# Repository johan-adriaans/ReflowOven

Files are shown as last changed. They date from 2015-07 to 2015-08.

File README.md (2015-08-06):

# ReflowOven
Arduino reflow oven voor de BEEA avond, 6 augustus 2015

De "bill-of-materials" staat [hier](board-v1/bill-of-materials.pdf).

## Opbouw reflow printje

Dit zijn de verbindingen op het bordje dat je gaat opbouwen:

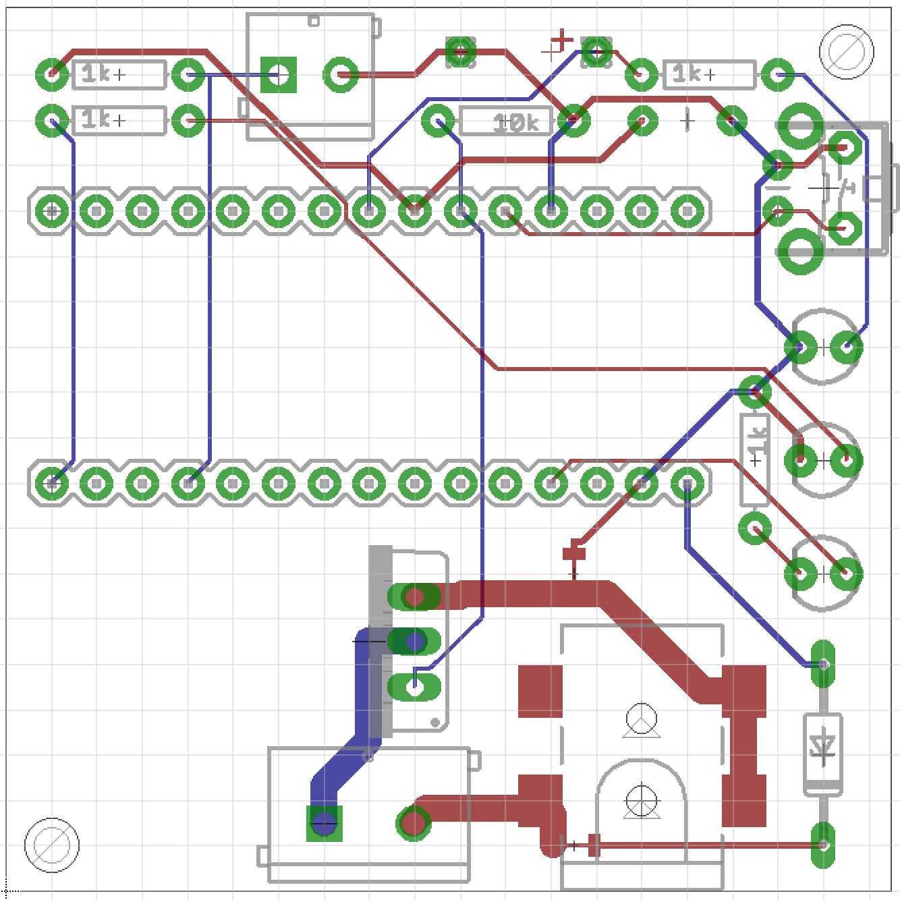
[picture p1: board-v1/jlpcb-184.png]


### Stap 1: alle lage componenten

Let op de polariteit van de 3 LEDs en de zener diode!

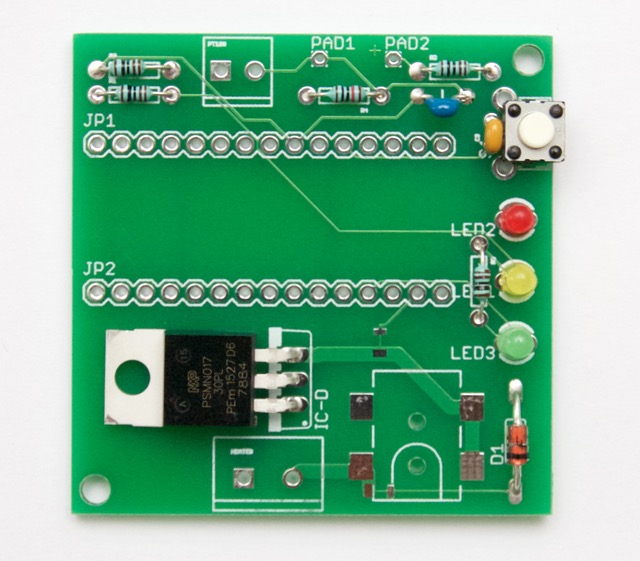
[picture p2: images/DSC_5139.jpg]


Het knopje is een andere dan oorspronkelijk op de print voorzien is.

### Stap 2: drie connectoren

DC jack, kleine sensor aansluiting, grote heater aansluting:

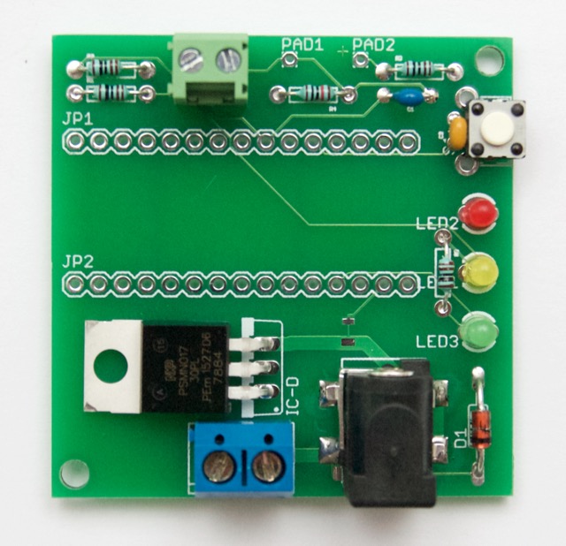
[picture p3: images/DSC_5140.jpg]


Goed vastsolderen, vooral die DC voeding jack.

### Stap 3: Arduino Nano microcontroller

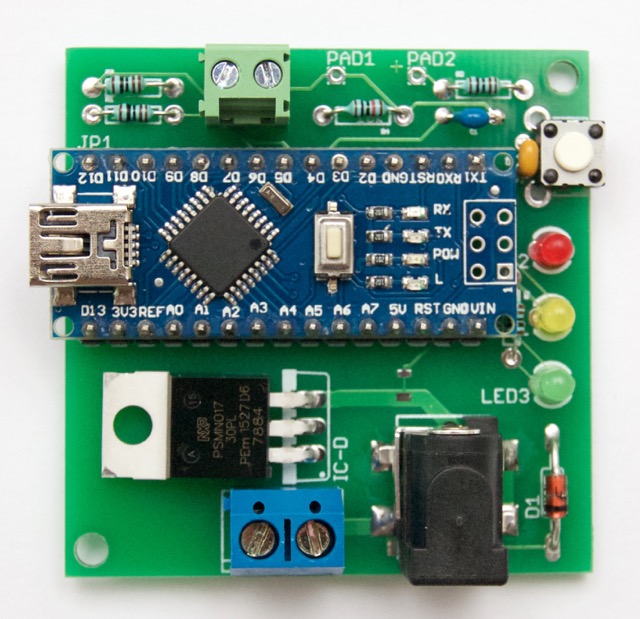
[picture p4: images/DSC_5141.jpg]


Pennen afknippen, zodat de onderkant redelijk vlak is.

### Stap 4: zoemer en extra dikke condensator

Let op polariteit van beide componenten:

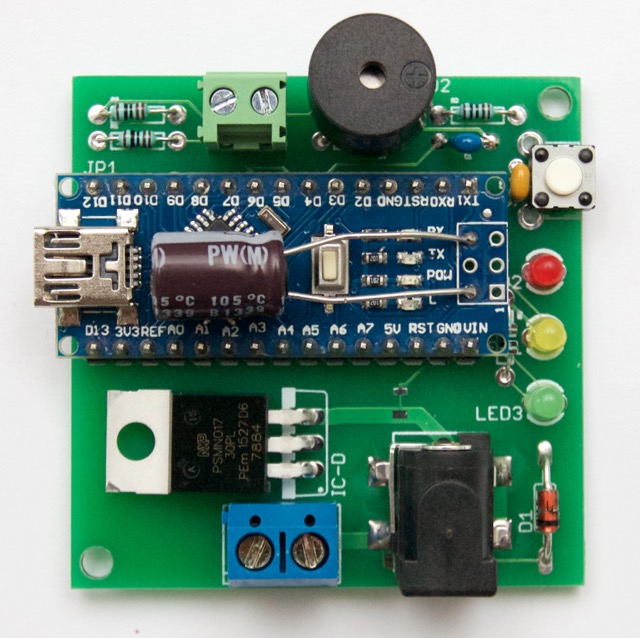
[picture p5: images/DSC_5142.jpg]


### Stap 5: sensor + heater

De sensor in de groene schroefklemmen, heater in de blauwe:

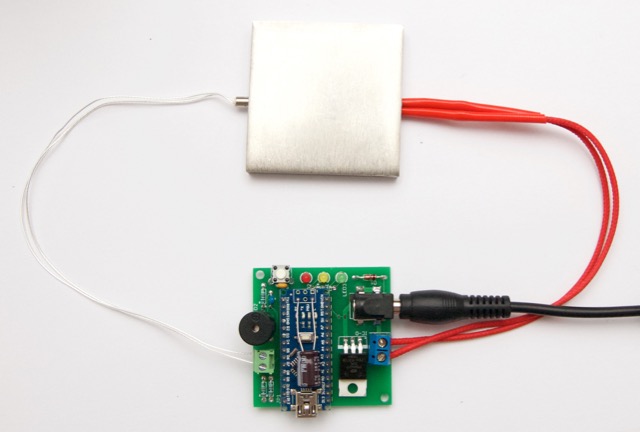
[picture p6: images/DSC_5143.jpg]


Draden blank maken, liefst strippen en vertinnen, dan goed vastschroeven.

### Stap 6: software

Er moet een Arduino "sketch" in de Arduino worden geinstalleerd.  
Dat gaat via de USB stekker, en een USB driver voor de CH341 chip.  
De groene LED is altijd aan als de interne 5V regelaar stroom krijgt.

**Niet** de 19V voeding aansluiten tijdens deze actie!

### Stap 7

Controleren, controleren, controleren. En dan: _nog een laatste keertje..._  
Als bijvoorbeeld de zener verkeerd om zit, krijg je gegarandeerd vuurwerk.  
Pas als je zeker weet dat de zaak klopt, de 19V adapter inprikken.

Als alles goed aangesloten en ingesteld is, begint het plaatje warm te worden.  
Zet de zaak **alleen** aan als de heater goed in het koelblok geklemd zit!

## Opbouw demo bordje

...

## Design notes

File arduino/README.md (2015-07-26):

# ReflowOven
Arduino reflow oven voor de BEEA avond

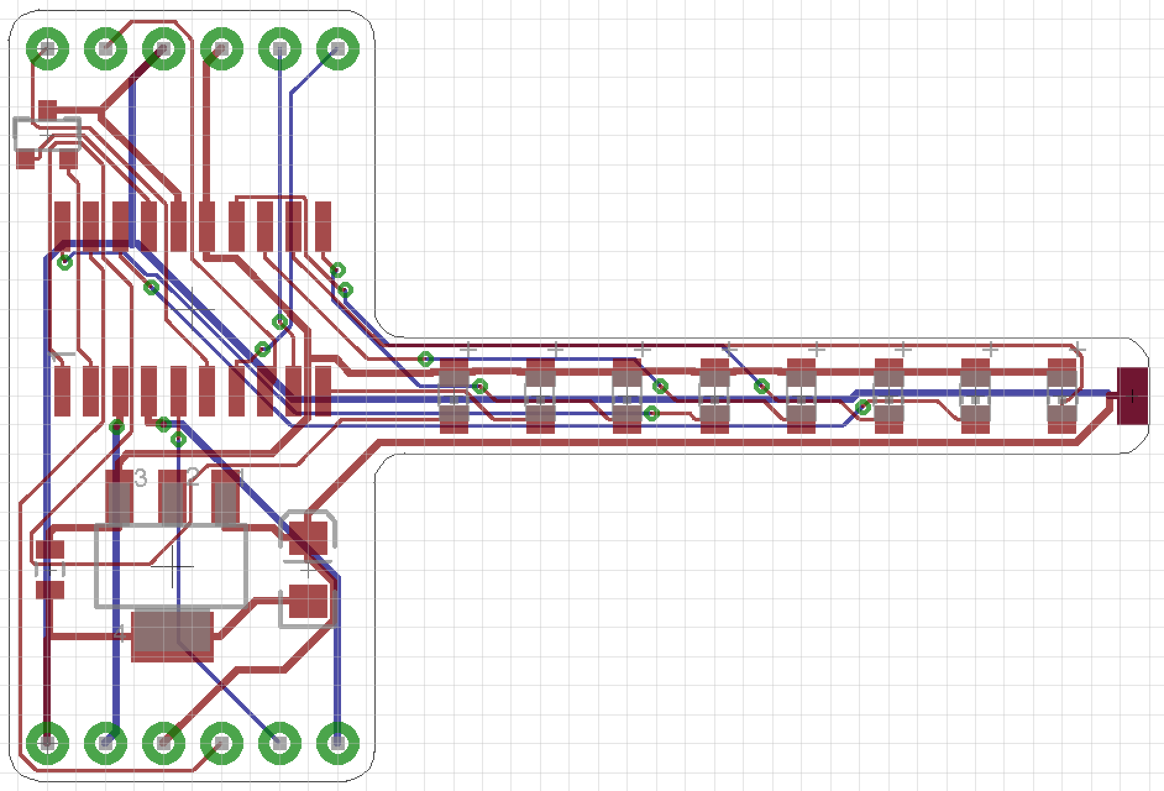
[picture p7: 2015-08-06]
demo-v1/jlpcb-183.png

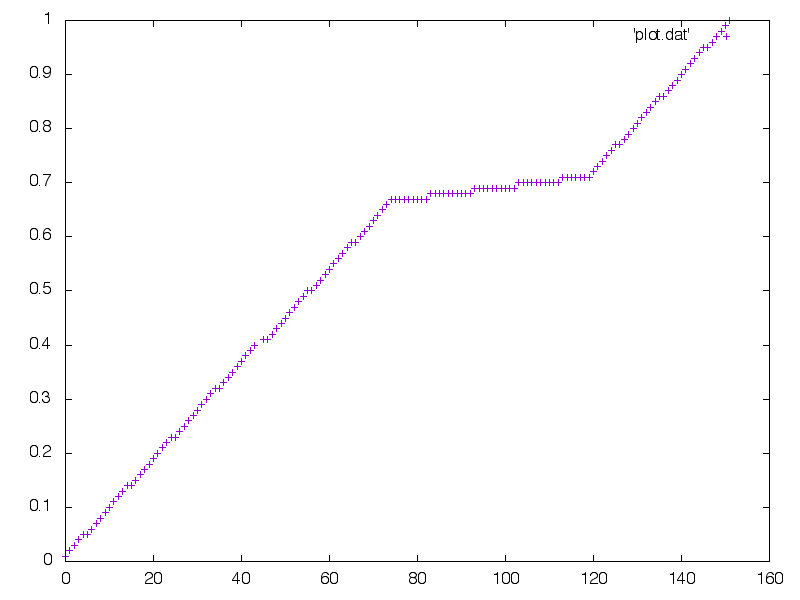
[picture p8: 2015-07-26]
research/plot.png

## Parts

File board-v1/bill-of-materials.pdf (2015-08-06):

Component | Cost US$
Arduino Nano clone (eBay) | 2.68
buzzer | 0.16
heater cartridge 40W | 2.24
PT100 temperature sensor | 1.02
zener 10V 1W | 0.40
capacitor 470 µF 10V | 0.15
MOSFET PSMN017-30PL | 0.75
power supply 19V 65W | 11.00
capacitor 1 µF 16V | 0.23
4x resistor 1 kΩ 1/8W | 0.15
resistor 10 kΩ 1/8W | 0.04
2x screw terminals | 0.60
3x LED 3mm | 1.50
DC power jack 5.5/2.1 mm | 0.90
push button | 0.23
printed circuit board | 2.10
Electronics | 24.15
LPC812 SOIC µ-controller | 1.80
8x blue LED | 2.80
hall effect sensor S-5716 | 1.05
regulator MIC5203-3.6 | 0.95
capacitor 1 µF ceramic | 0.23
capacitor 10 µF ceramic | 0.27
USB cable | 1.00
printed circuit board | 2.10
Demo board | 10.20
tweezers | 0.99
glow-in-the-dark paint | 1.69
heat sink | 1.77
solder paste low-melt 138°C | 1.65
55x55x8mm aluminium block | 2.00
syringe 1 ml | 1.00
2x syringe nozzle | 1.10
ceramic tile | 1.00
crème brûlée + schaaltje :) | 1.10
Mechanical | 12.30
Various | 5.00
Nano Reflow v1 - BEEA | 51.65

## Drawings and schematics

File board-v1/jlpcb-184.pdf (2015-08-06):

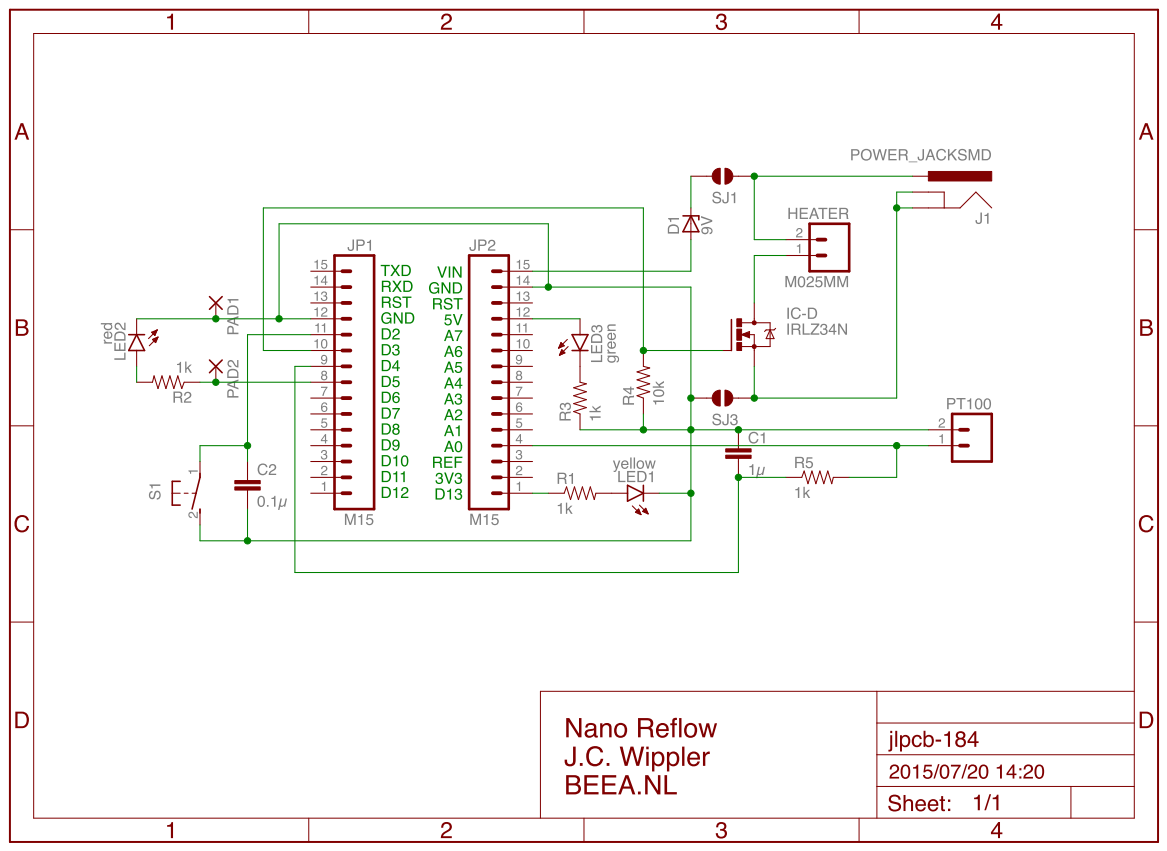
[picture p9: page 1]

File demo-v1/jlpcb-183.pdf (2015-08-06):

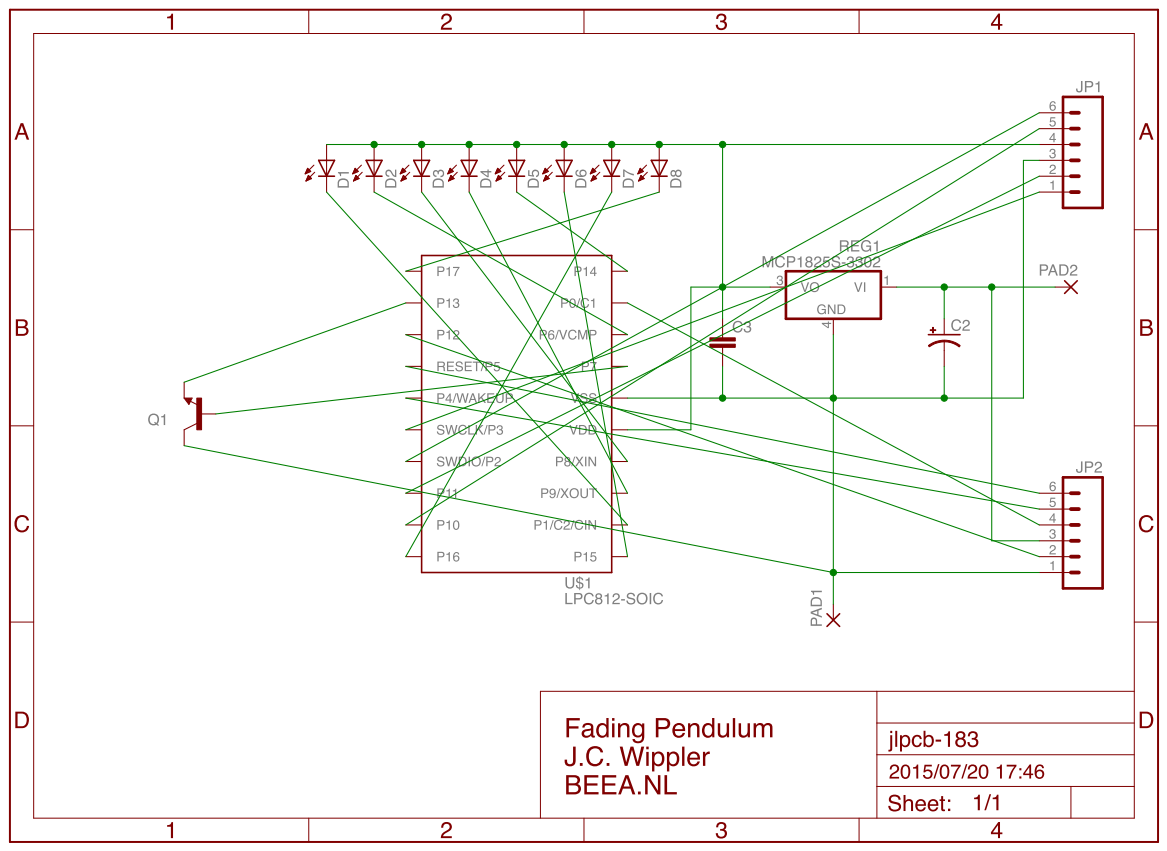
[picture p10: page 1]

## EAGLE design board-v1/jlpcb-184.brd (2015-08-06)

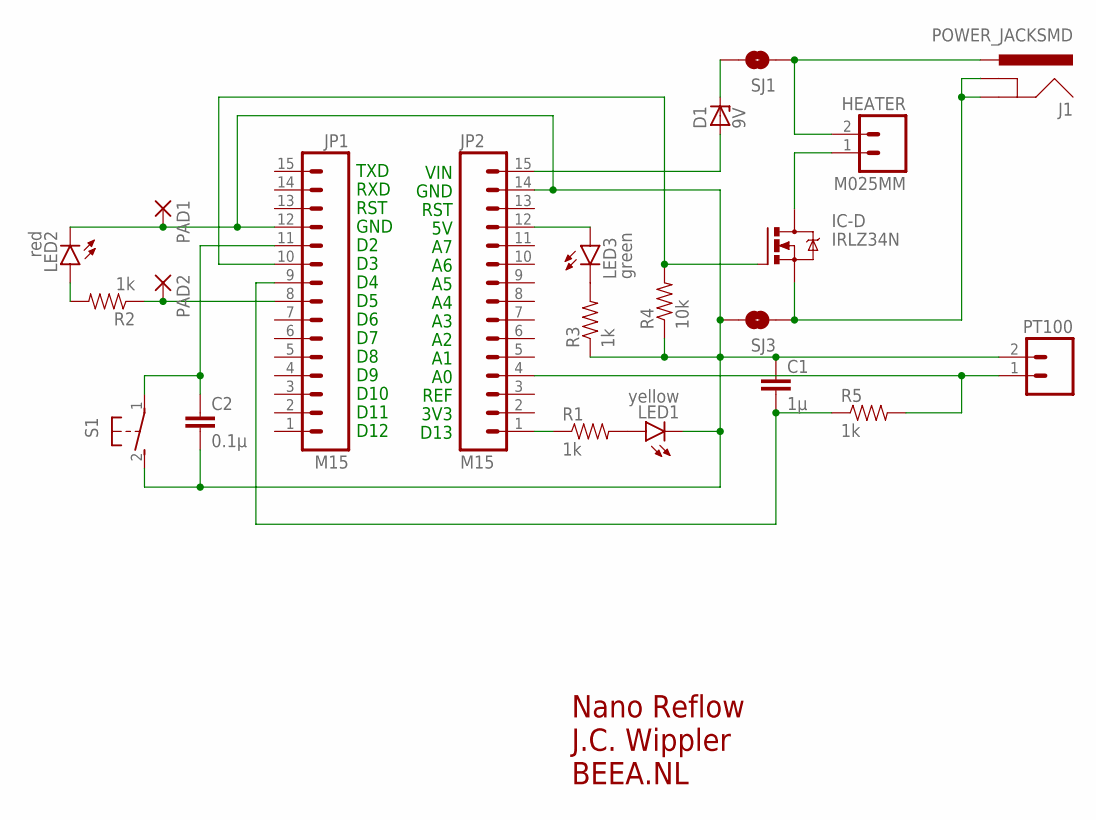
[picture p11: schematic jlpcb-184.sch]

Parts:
C1: 1µ; CAP-PTH-5MM
C2: 0.1µ; CAP-PTH-SMALL
D1: 9V; DO35Z10
HEATER: M025MM; SCREWTERMINAL-5MM-2
IC-D: IRLZ34N; TO220BV
J1: POWER_JACKSMD; POWER_JACK_SMD
JP1, JP2: M15; 1X15
LED1: yellow; LED3MM
LED2: red; LED3MM
LED3: green; LED3MM
PAD1, PAD2: 1,6/0,8
PT100: M023.5MM; SCREWTERMINAL-3.5MM-2
R1, R2, R3, R5: 1k; AXIAL-0.3
R4: 10k; AXIAL-0.3
S1: 31-XX; B3F-31XX
SJ1, SJ3: SOLDERJUMPERTRACE; SJ_2S-TRACE

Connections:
unnamed: D1.A, JP2.15
unnamed: D1.C, SJ1.2
unnamed: HEATER.1, IC-D.D
unnamed: IC-D.S, J1.GND (GNDBREAK), J1.P$4 (GND), SJ3.1
unnamed: C1.1, C2.2, JP1.12, JP2.14, LED1.K (C), LED2.K (C), PAD1.1, PT100.2, R3.P$1 (1), R4.P$1 (1), S1.2 (S), SJ3.2
unnamed: HEATER.2, J1.VIN0 (PWR), SJ1.1
unnamed: LED2.A, R2.P$2 (2)
unnamed: LED1.A, R1.P$2 (2)
unnamed: JP2.1, R1.P$1 (1)
unnamed: JP2.4, PT100.1, R5.P$2 (2)
unnamed: LED3.K (C), R3.P$2 (2)
unnamed: JP2.12, LED3.A
unnamed: IC-D.G, JP1.10, R4.P$2 (2)
unnamed: JP1.8, PAD2.1, R2.P$1 (1)
unnamed: C1.2, JP1.9, R5.P$1 (1)
unnamed: C2.1, JP1.11, S1.1

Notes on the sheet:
D12
D11
D10
GND
RST
RXD
TXD
D13
3V3
REF
VIN
Nano Reflow J.C. Wippler BEEA.NL

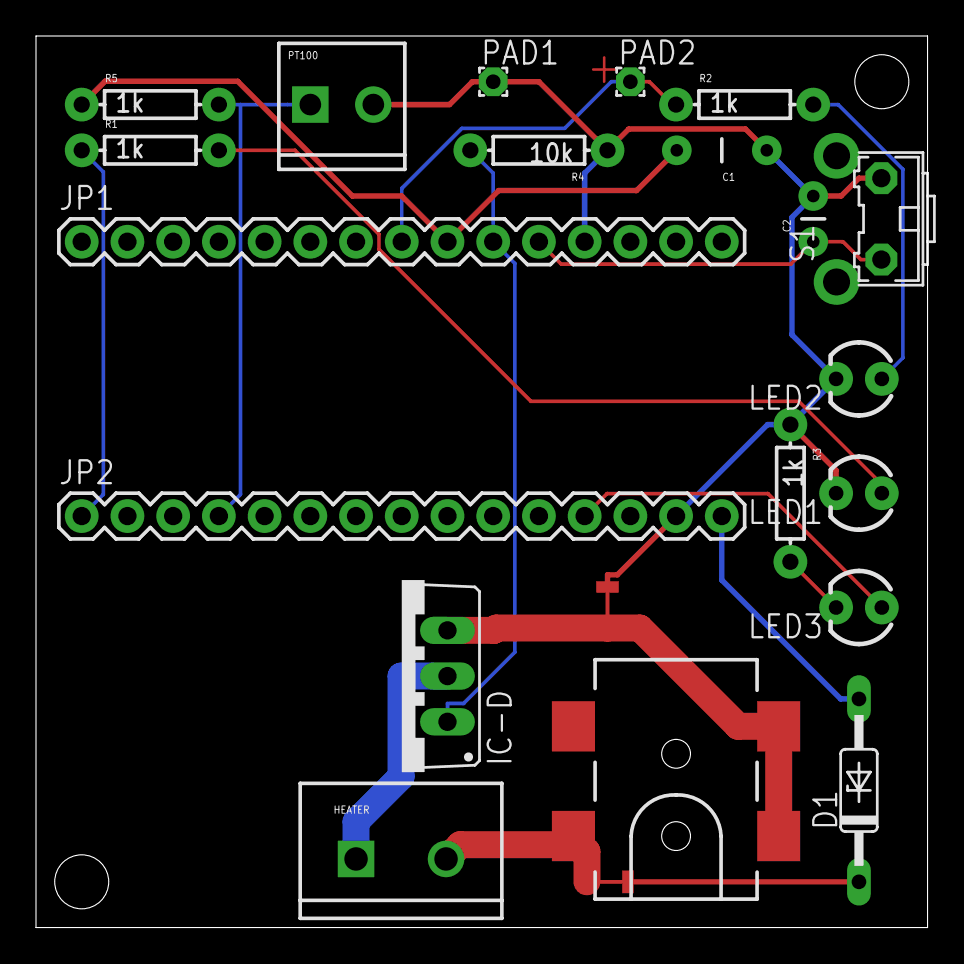
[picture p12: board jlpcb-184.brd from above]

Board: 2 copper layers, 49.5 x 49.5 mm, 22 parts (0 on the bottom side), 16 nets.

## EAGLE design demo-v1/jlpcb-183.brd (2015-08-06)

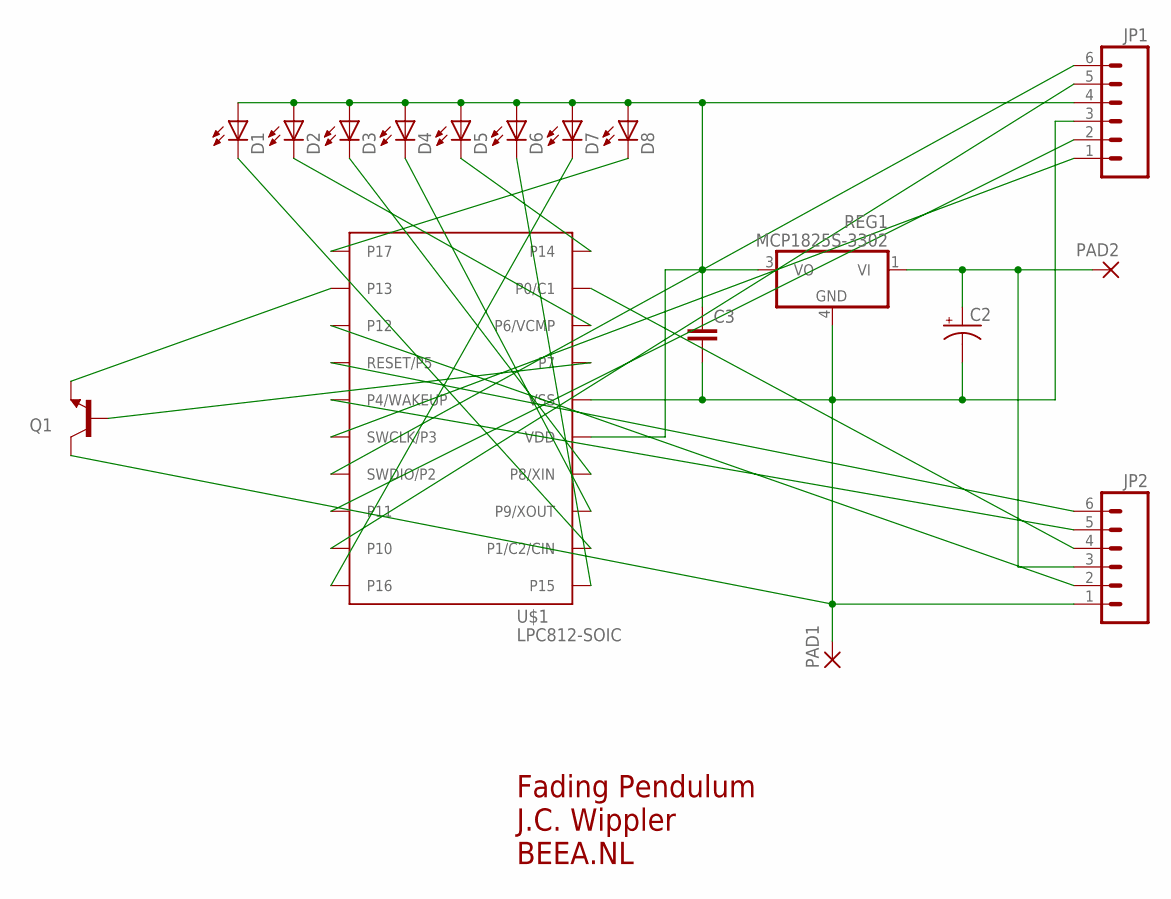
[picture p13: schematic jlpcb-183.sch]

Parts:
C2: CAP_POL1206; EIA3216
C3: CAP0805; 0805
D1, D2, D3, D4, D5, D6, D7, D8: LEDCHIP-LED0805; CHIP-LED0805
JP1, JP2: M06NO_SILK_FEMALE_PTH; 1X06_NO_SILK
PAD1, PAD2: SMD2; SMD1,27-2,54
Q1: TRANSISTOR_NPNSOT23-3; SOT23-3
REG1: MCP1825S-3302; SOT223
U$1: LPC812-SOIC; SOIC20

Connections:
unnamed: D1.C, U$1.12 (P1/C2/CIN)
unnamed: D2.C, U$1.18 (P6/VCMP)
unnamed: D3.C, U$1.14 (P8/XIN)
unnamed: D4.C, U$1.13 (P9/XOUT)
unnamed: D5.C, U$1.20 (P14)
unnamed: D6.C, U$1.11 (P15)
unnamed: D7.C, U$1.10 (P16)
unnamed: D8.C, U$1.1 (P17)
unnamed: C3.1, D1.A, D2.A, D3.A, D4.A, D5.A, D6.A, D7.A, D8.A, JP1.4, REG1.3 (VO), U$1.15 (VDD)
unnamed: C2.C (-), C3.2, JP1.3, JP2.1, PAD1.1, Q1.3 (C), REG1.4 (GND), U$1.16 (VSS)
unnamed: C2.A (+), JP2.3, PAD2.1, REG1.1 (VI)
unnamed: JP2.2, U$1.3 (P12)
unnamed: JP2.6, U$1.4 (RESET/P5)
unnamed: JP2.5, U$1.5 (P4/WAKEUP)
unnamed: JP2.4, U$1.19 (P0/C1)
unnamed: JP1.5, U$1.9 (P10)
unnamed: JP1.2, U$1.8 (P11)
unnamed: JP1.6, U$1.7 (SWDIO/P2)
unnamed: JP1.1, U$1.6 (SWCLK/P3)
unnamed: Q1.2 (E), U$1.2 (P13)
unnamed: Q1.1 (B), U$1.17 (P7)

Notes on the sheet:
Fading Pendulum J.C. Wippler BEEA.NL

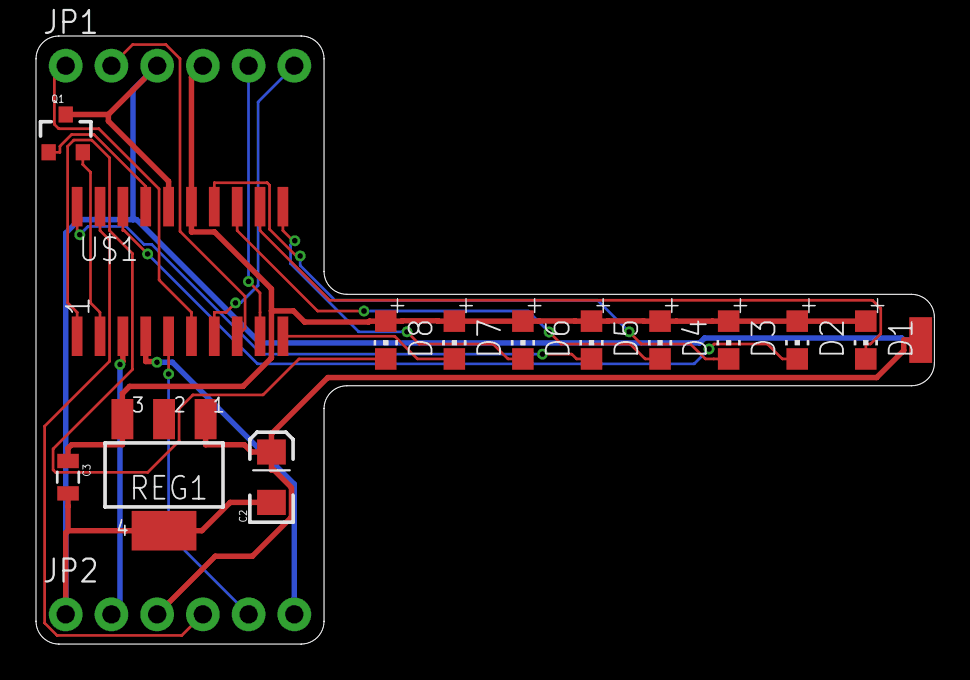
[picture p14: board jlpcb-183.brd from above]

Board: 2 copper layers, 49.9 x 33.8 mm, 17 parts (1 on the bottom side), 21 nets.

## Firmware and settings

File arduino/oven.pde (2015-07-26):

#define STAGE_INITIAL 1  // Heat up to ~0.75 of target temp
#define STAGE_SOAK 2     // Soak at ~0.75 of temp for TIME_TO_SOAK seconds
#define STAGE_END 3      // Heat up to 1
#define STAGE_FINISHED 4 // Shut down heat and play buzzer
#define STAGE_ERROR 255  // Shut down heat and stop

#define MODE_NORMAL 1    // Normal operation
#define MODE_CALIBRATE 2 // Calibration mode, blink led and listen for pushbutton

// Heat profiles
// Loodvrij soldeer
//#define SOAK_TEMPERATURE 180   // At which temperature shall we start soaking?
//#define TARGET_TEMPERATURE 250 // Target temperature..

// Loodhoudende soldeer
//#define SOAK_TEMPERATURE 140
//#define TARGET_TEMPERATURE 220

// Laagsmeltpunt soldeer
#define SOAK_TEMPERATURE 110
#define TARGET_TEMPERATURE 160

#define MAX_HEAT_OFFSET 20     // Area around target heat used for calculating heater power
#define MAX_HEATER_RATE 200    // Max PWM rate for heaterPin

#define TIME_TO_SOAK 45.0 // Seconds to soak (Needs to be a float)
#define TIME_BEFORE_SOAK 90.0 // Try to reach SOAK_TEMPERATURE in TIME_BEFORE_SOAK seconds

// Pinout
int pushbuttonPin = 2;
int heaterPin = 3;
int sensorPowerPin = 4;
int buzzerPin = 5;
int ledPin = 13;
int sensorInputPin = 0;

int seconds = 0;
int pushbuttonState = 0;
int soakTimeStart = 0;
int soakTime = 0;
float heaterPower = 0;
float temperature = 0;
float targetTemperature = 0;

// Start in normal mode
int mode = MODE_NORMAL;
int stage = STAGE_INITIAL;

void setup()
{
  pinMode( heaterPin, OUTPUT );
  pinMode( buzzerPin, OUTPUT );
  pinMode( ledPin, OUTPUT );
  pinMode( pushbuttonPin, INPUT_PULLUP ); // Pull-up inverts HIGH/LOW state

  // Setup sensor
  //ADMUX = 0xC0; // REFS = 3, use 1.1V bandgap as reference
  //analogReference(INTERNAL1V1);
  analogReference( 3 );
  analogRead( sensorInputPin );
  pinMode( sensorPowerPin, OUTPUT );
  digitalWrite( sensorPowerPin, 1);

  Serial.begin( 57600 );
  Serial.println( "\n[Reflow oven]" );
  Serial.println( "##### INITIAL STAGE #####" );
}

int readTemperature ()
{
  // 380 ≈ 25°C and 765 ≈ 200°C
  int adc = analogRead( sensorInputPin );

  static int avg = 0;
  if ( avg == 0 ) {
    avg = adc;
  }
  avg = (3 * avg + adc) / 4;

  // assumes linear relationship between adc and temp, this is not correct!
  return map( avg, 380, 765, 25, 200 );
}

void loop()
{
  // Error occured, needs reset
  if ( stage == STAGE_ERROR ) return;

  static int lastUpdate;
  seconds = millis() / 1000;

  // Read button
  pushbuttonState = digitalRead( pushbuttonPin );
  if ( pushbuttonState == LOW && seconds < 5 ) {
    Serial.println( "Starting calibration mode" );
    mode = MODE_CALIBRATE;
  } else if ( pushbuttonState == LOW && seconds > 30 && mode == MODE_CALIBRATE ) {
    Serial.println( "Calibrated" );
    // TODO: Write sensor measurement to EPROM and shut down
  }

  if ( stage == STAGE_INITIAL ) {
    if ( temperature >= SOAK_TEMPERATURE && stage == STAGE_INITIAL ) {
      Serial.println( "##### SOAK STAGE #####" );
      soakTimeStart = seconds;
      stage = STAGE_SOAK;
    }

    targetTemperature = (seconds / TIME_BEFORE_SOAK) * SOAK_TEMPERATURE;
    heaterPower = (targetTemperature - temperature) / MAX_HEAT_OFFSET;
  } else if ( stage == STAGE_SOAK ) {
    soakTime = seconds - soakTimeStart;
    if ( soakTime >= TIME_TO_SOAK ) {
      Serial.println( "##### END STAGE #####" );
      stage = STAGE_END;
    }

    targetTemperature = SOAK_TEMPERATURE + ((soakTime / TIME_TO_SOAK) * 10);
    heaterPower = ( targetTemperature - temperature ) / MAX_HEAT_OFFSET;
  } else if ( stage == STAGE_END ) {
    heaterPower = 1;
  }

  if ( temperature >= TARGET_TEMPERATURE && stage < STAGE_FINISHED ) {
    Serial.println( "##### FINISHED #####" );
    heaterPower = 0;
    stage = STAGE_FINISHED;
  }

  if ( seconds != lastUpdate ) {
    if ( temperature > 300 ) {
      Serial.println( "Error: heat > 300 - Please attach sensor and reset" );
      stage = STAGE_ERROR;
      digitalWrite( ledPin, HIGH ); // Red alert! :)
      heaterPower = 0; // Turn heater off!
    }

    // Beep a few times
    static int beeps;
    if ( stage == STAGE_FINISHED && beeps < 6 ) {
      static bool beep;
      beep = !beep;
      digitalWrite( buzzerPin, beep ? HIGH : LOW );
      Serial.println( "Beep..." );
      beeps++;
    }

    // Apply heat
    int heaterLevel = min( 1, max( 0, heaterPower ) ) * MAX_HEATER_RATE;
    analogWrite( heaterPin, heaterLevel );
    if ( stage < STAGE_ERROR ) {
      digitalWrite( ledPin, heaterLevel > 1 ? HIGH : LOW );
    }

    // Read temperature
    temperature = readTemperature();

    Serial.print( seconds );
    Serial.print( " " );
    Serial.print( "temp:" );
    Serial.print( temperature );

    Serial.print( " " );

    Serial.print( "heater:" );
    Serial.println( heaterLevel );
    lastUpdate = seconds;
  }
}

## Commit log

2015-07-26 Heater now advertises power level through PWM on pin13. Changed heat profile
2015-07-26 Heater level led did nog have a PWM port :)
2015-07-26 Added heat profiles (as comments)
2015-08-06 add boards and photos
    [jlpcb-183.brd, jlpcb-183.sch, jlpcb-184.brd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]
2015-08-06 add BOM
2015-08-06 add link to BOM

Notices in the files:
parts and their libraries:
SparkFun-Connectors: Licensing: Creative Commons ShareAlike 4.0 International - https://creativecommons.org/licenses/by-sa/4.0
